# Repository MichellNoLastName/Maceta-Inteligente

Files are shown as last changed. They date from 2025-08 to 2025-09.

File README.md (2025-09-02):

# 🌱 Maceta Inteligente para el Crecimiento de un Crisantemo

Este proyecto fue desarrollado como parte de la asignatura **Proyecto Integrador**, con el objetivo de diseñar y programar una **maceta inteligente** que monitorea y controla las condiciones ambientales necesarias para el óptimo crecimiento de un **crisantemo**.  

La maceta integra sensores, un sistema de riego automático, control de luz artificial y una interfaz LCD para mostrar información en tiempo real, todo gestionado mediante un **Arduino**.

---

## 🚀 Características principales

- 📊 **Monitoreo de temperatura y humedad ambiental** mediante un sensor **DHT11**.  
- 💧 **Control automático de riego** con bomba de agua y sensores de nivel de tanque.  
- ☀️ **Control de fotoperiodo** mediante un sistema de iluminación artificial, activado según el ciclo programado para la planta.  
- 🔔 **Alarmas sonoras** (buzzer) para advertencias de exceso/falta de agua, luz o temperatura.  
- 🖥️ **Pantalla LCD 20x4 con I2C**, que muestra:
  - Fecha y hora (RTC DS1307).  
  - Temperatura y humedad.  
  - Estado del tanque y la luz.  
  - Menú de configuración y selección de planta.  
- 🌼 **Base de datos de parámetros óptimos** para 3 plantas (incluyendo el crisantemo), con rangos de temperatura, humedad y fotoperiodo.  

---

## 🛠️ Componentes utilizados

- **Arduino UNO**  
- **Sensor DHT11** → temperatura y humedad ambiental  
- **Sensor de humedad de suelo** (analógico)  
- **Sensores de nivel de agua** (mínimo y máximo)  
- **Bomba de agua** + relevador para riego automático  
- **LED / lámpara de cultivo** para control de luminosidad  
- **Pantalla LCD 20x4 con módulo I2C**  
- **Módulo RTC DS1307** → control de fecha y hora  
- **Buzzer piezoeléctrico**  
- **Botones de navegación** (izquierda, derecha, enter)  

---

## 📋 Funcionalidades del software

1. **Selección de planta al inicio** (Crisantemo, Rosa de alabastro o Petunia).  
2. **Adquisición de datos en tiempo real** (temperatura, humedad, nivel de agua, fotoperiodo).  
3. **Acciones automáticas**:
   - Activa la bomba de riego si la humedad del suelo es baja.  
   - Activa o apaga la luz según el ciclo fotoperiódico de la planta seleccionada.  
   - Alarmas en caso de exceso de temperatura, sequedad extrema o falta de agua en el tanque.  
4. **Interfaz de usuario en LCD** con menús:
   - Estado actual del sistema.  
   - Parámetros de la planta seleccionada.  
   - Información del sustrato recomendado.  
   - Control manual de la luz.  
   - Activar o desactivar modo silencioso.  
5. **Uso de RTC DS1307** para el control exacto de horarios.  

---

## 📂 Estructura del código

El programa está desarrollado en **C++ para Arduino**, con las siguientes secciones principales:

- Configuración de **pines y sensores**.  
- Inicialización de **LCD y RTC**.  
- **Menú de selección de planta** al inicio.  
- **Loop principal**:
  - Lectura de sensores.  
  - Actualización de pantalla LCD.  
  - Ejecución de alarmas y acciones automáticas.  
- Funciones auxiliares:
  - `read_ds1307()` → lectura del reloj en tiempo real.  
  - `bcd2bin()` → conversión de valores BCD.  
  - `antireboot()` → debounce de botones.  

---

## 📊 Parámetros configurados para el Crisantemo

- 🌡️ **Temperatura óptima**: 10°C – 32°C  
- 💧 **Humedad óptima del suelo**: 65% – 70%  
- ☀️ **Fotoperiodo**: 7:00 a 18:00  
- 🌱 **Sustrato recomendado**:  
  - 2/3 tierra de jardín  
  - 1/3 composta  

---

## 📸 Ejemplo del flujo de trabajo

1. Al encender el sistema, el usuario selecciona la planta en el menú LCD.  
2. El sistema comienza a **monitorear los sensores** y controla automáticamente el riego y la luz.  
3. Si la planta está en riesgo (frío, calor, exceso de agua, falta de tanque), se activa el **buzzer y mensajes en LCD**.  
4. El usuario puede navegar en el menú para ver información o activar/desactivar funciones manualmente.  

---

## 📌 Futuras mejoras

- Comunicación con una **aplicación móvil** vía Bluetooth o WiFi.  
- Registro de datos en **tarjeta SD** para análisis histórico.  
- Implementación de un **modo automático de aprendizaje** que ajuste parámetros según el crecimiento real de la planta.  

---

## 👨‍💻 Autores

Este proyecto fue desarrollado por estudiantes de la asignatura **Proyecto Integrador**, con el objetivo de aplicar conocimientos en:  
- Programación de microcontroladores.  
- Electrónica y sensores.  
- Automatización y control ambiental.  

---
📖 **Asignatura:** Proyecto Integrador  
🌼 **Planta principal de estudio:** Crisantemo  
⚡ **Tecnologías usadas:** Arduino, C++, Electrónica de control  

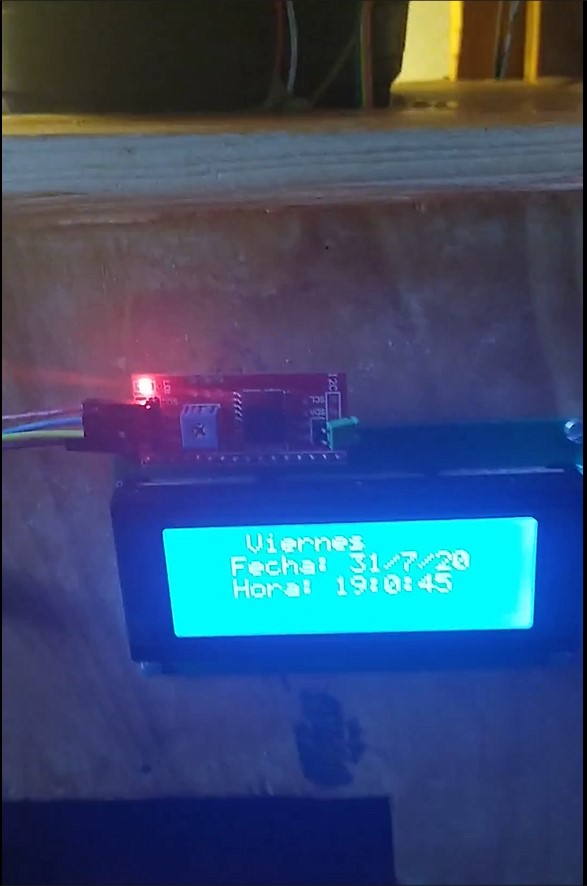
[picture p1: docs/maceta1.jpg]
Maceta 1

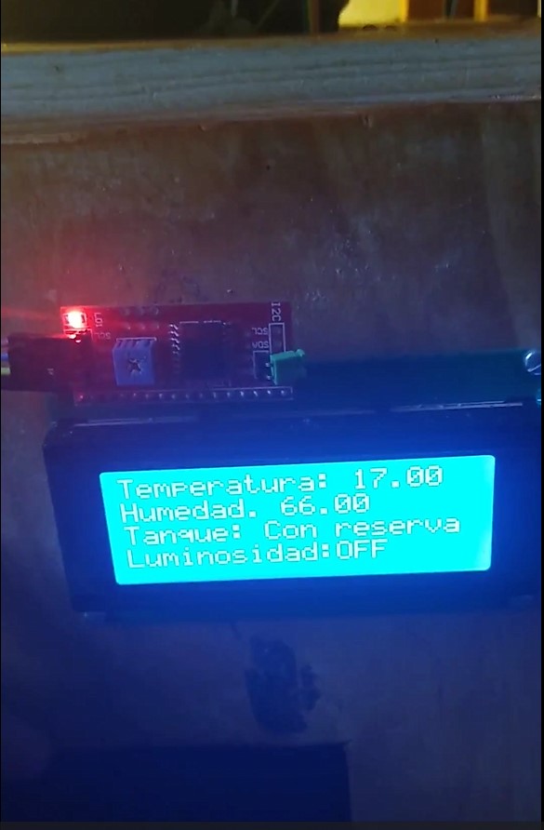
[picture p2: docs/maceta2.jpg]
Maceta 2

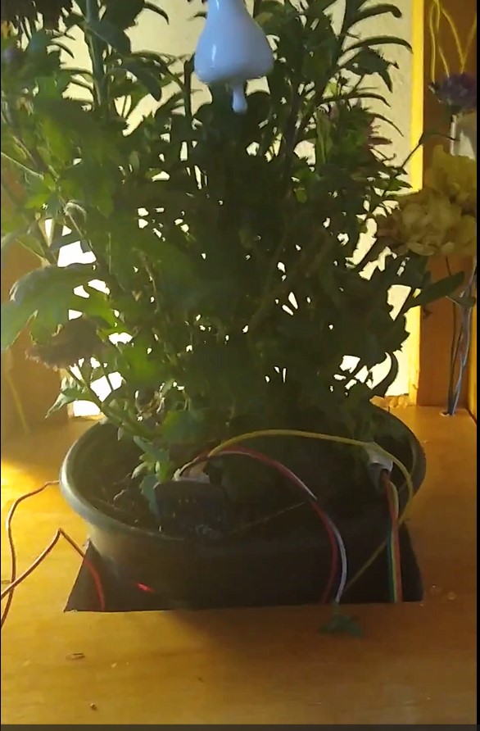
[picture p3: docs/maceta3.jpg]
Maceta 3

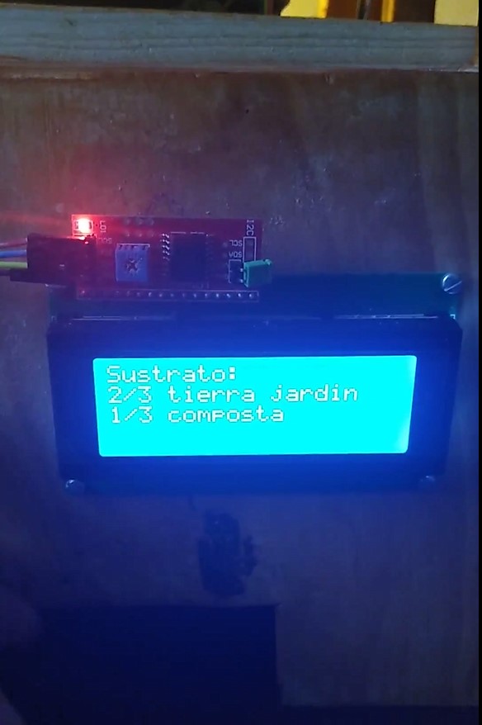
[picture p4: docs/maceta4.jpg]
Maceta 4

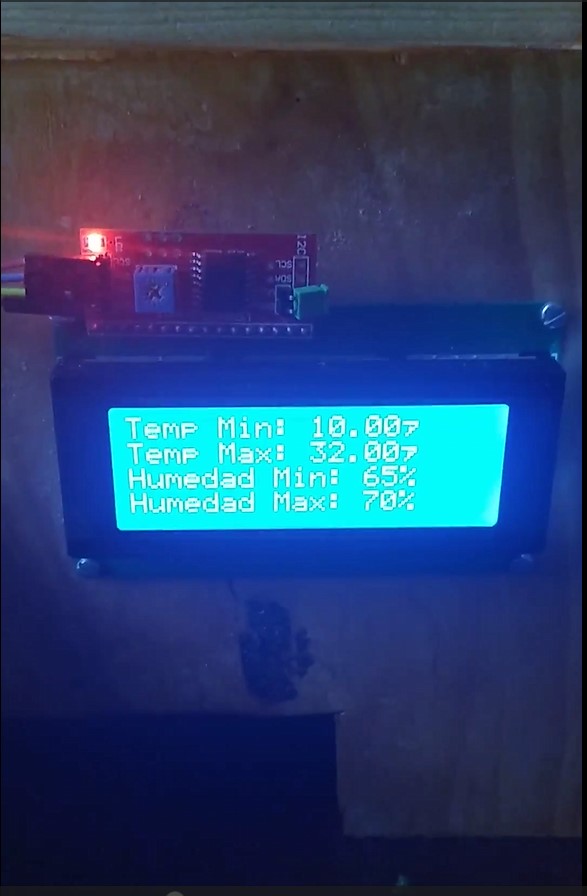
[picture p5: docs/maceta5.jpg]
Maceta 5

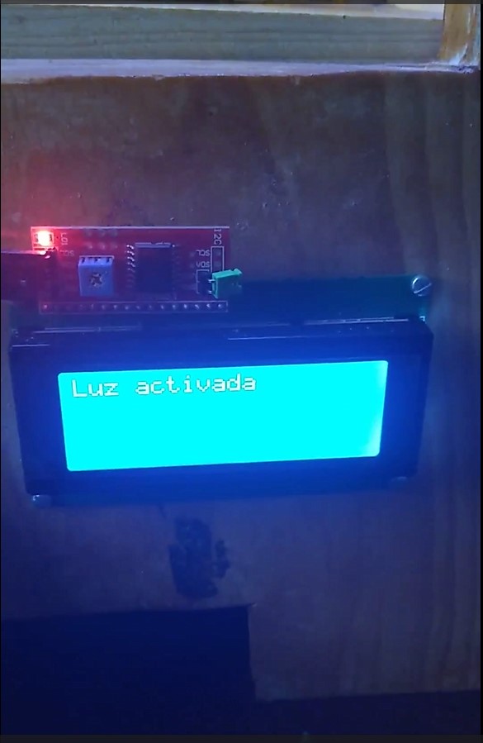
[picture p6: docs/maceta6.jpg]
Maceta 6

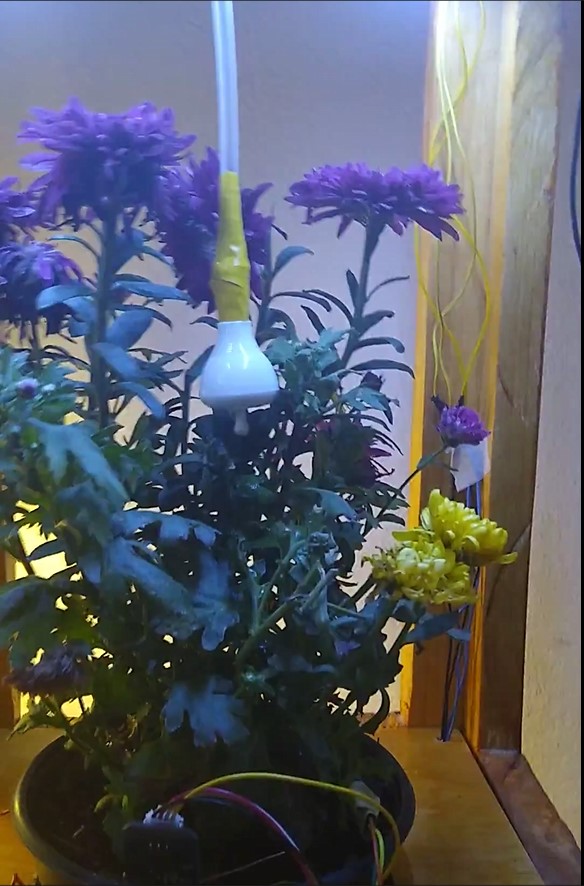
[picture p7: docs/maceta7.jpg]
Maceta 7

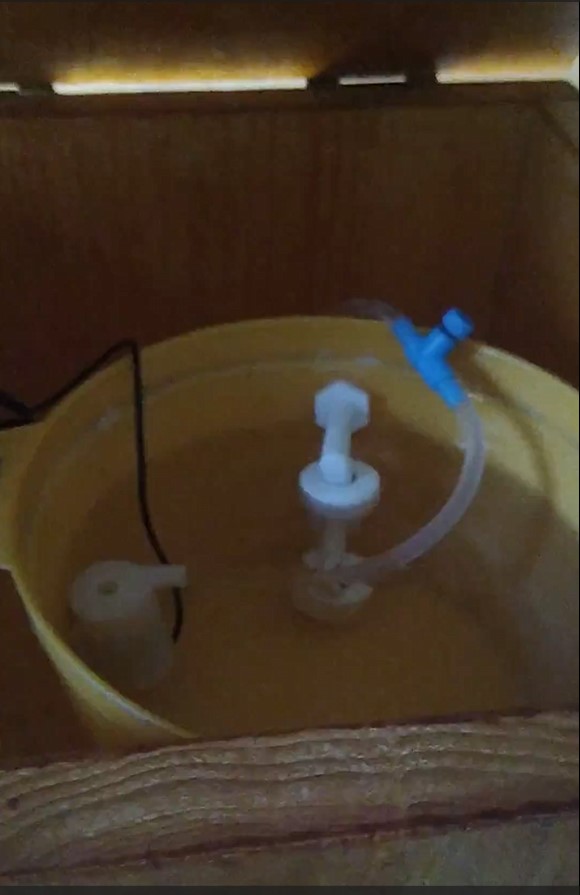
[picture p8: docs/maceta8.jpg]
Maceta 8


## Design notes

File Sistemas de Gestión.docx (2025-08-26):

Sistemas de Gestión

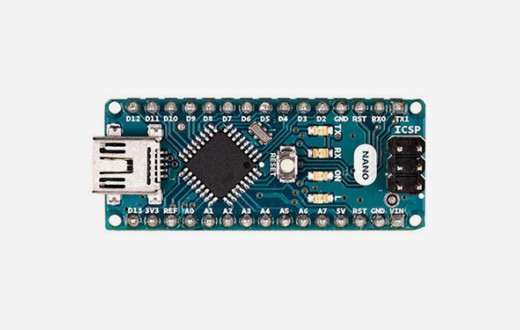
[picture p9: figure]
Arduino Nano

Arduino NANO | | https://store.arduino.cc/usa/arduino-nano

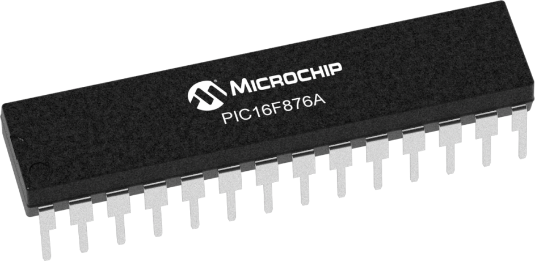
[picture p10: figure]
Resultado de imagen de pic16f876a

PIC16F876A | | https://ww1.microchip.com/downloads/en/devicedoc/39582b.pdf

Sistema de Adquisición de Datos

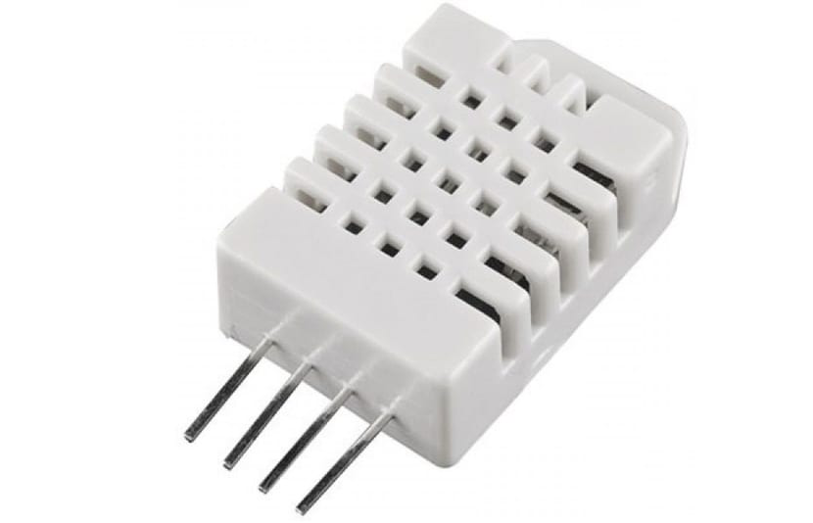
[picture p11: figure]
Resultado de imagen de dht22

DHT22 | | https://naylampmechatronics.com/sensores-temperatura-y-humedad/58-sensor-de-temperatura-y-humedad-relativa-dht22-am2302.html

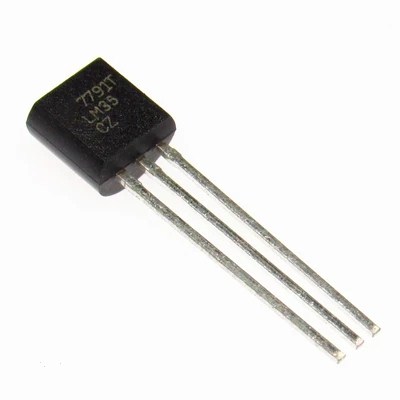
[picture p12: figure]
Resultado de imagen de lm35c

LM35C | | http://www.ti.com/lit/ds/symlink/lm35.pdf

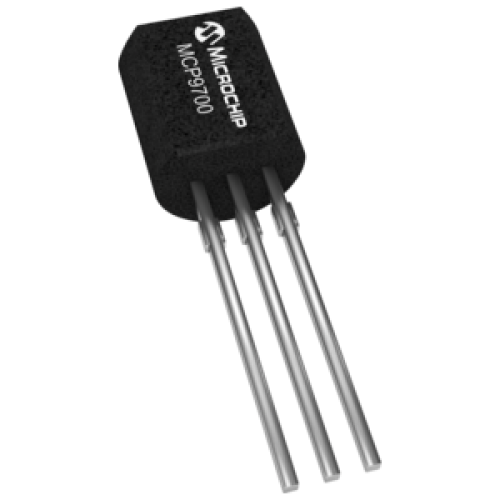
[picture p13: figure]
Resultado de imagen de mcp9700

MCP9700 | | http://ww1.microchip.com/downloads/en/devicedoc/20001942g.pdf

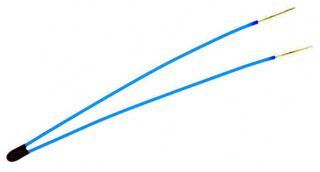
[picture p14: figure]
Resultado de imagen de termistor

NTC B57861S | | https://mexico.newark.com/epcos/b57861s0303f040/thermistor-aec-q200-ntc-30k-th/dp/46WX1275

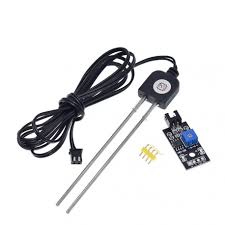
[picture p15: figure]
Resultado de imagen de sensores de humedad de suelo

Sensor de Humedad RFN | | https://articulo.mercadolibre.com.mx/MLM-705838733-sensor-de-humedad-en-suelo-tierra-con-sonda-arduino-_JM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

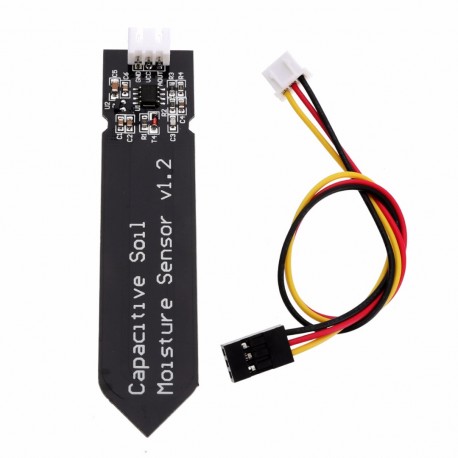
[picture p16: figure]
Sensor Capacitivo de Humedad de Suelo v1.2

Sensor de Humedad Capacitivo | | https://maxelectronica.cl/temperatura-y-humedad/519-sensor-capacitivo-de-humedad-de-suelo-v12.html

Interfaz Grafica

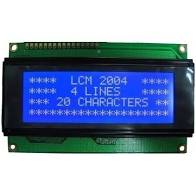
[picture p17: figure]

LCD 20x4 | | https://articulo.mercadolibre.com.mx/MLM-748112446-display-lcd-20x4-arduino-_JM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

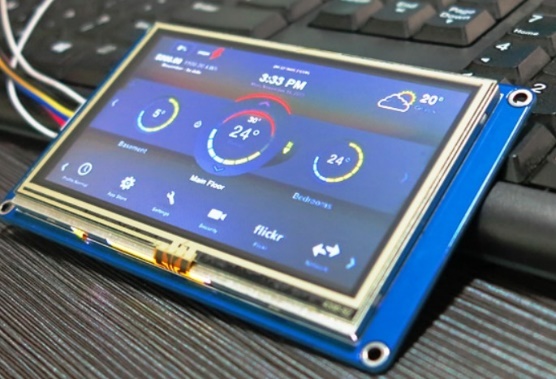
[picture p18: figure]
Resultado de imagen de pantalla nextion

Pantalla Táctil Nextion 2.4 | | https://nextion.tech/

Sistema de Abastecimiento de Agua

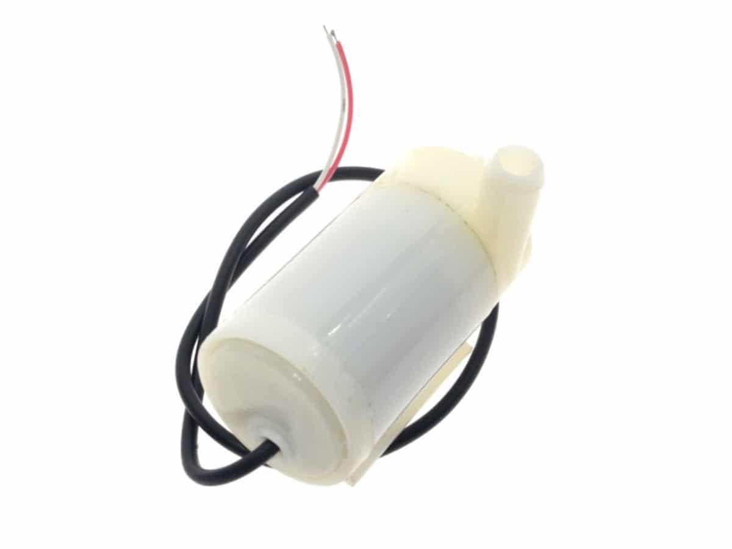
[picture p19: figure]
Resultado de imagen de bomba de agua arduino

Bomba de Agua 6V | | https://www.cdmxelectronica.com/producto/bomba-de-agua-sumergible-arduino-70-120l-h-micro-motor/

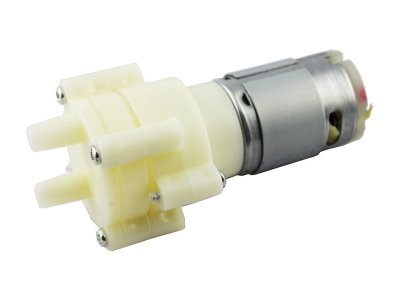
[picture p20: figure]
Resultado de imagen de bomba de agua arduino

Bomba de Agua 12V | | https://articulo.mercadolibre.com.mx/MLM-754341525-mini-bomba-de-agua-de-diafragma-12v-arduino-pic-_JM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

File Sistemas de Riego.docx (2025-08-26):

# Sistemas de Riego

El riego por goteo es muy utilizado en cultivos de hortalizas como jitomate, habanero etc. Aunue también es utilizado oara cultivar hiervas aromáticas y flores.

- Riego por Goteo
1. Goteros Turbulentos:

El gotero turbulento funciona variando los litros por minuto del caudal dependiendo de la presión que esté ejerciendo. Esto implica que no es adecuado cuando hay grandes niveles o pendientes pues en tales casos, el último gotero de la línea no va a recibir el mismo flujo de agua que los primeros.

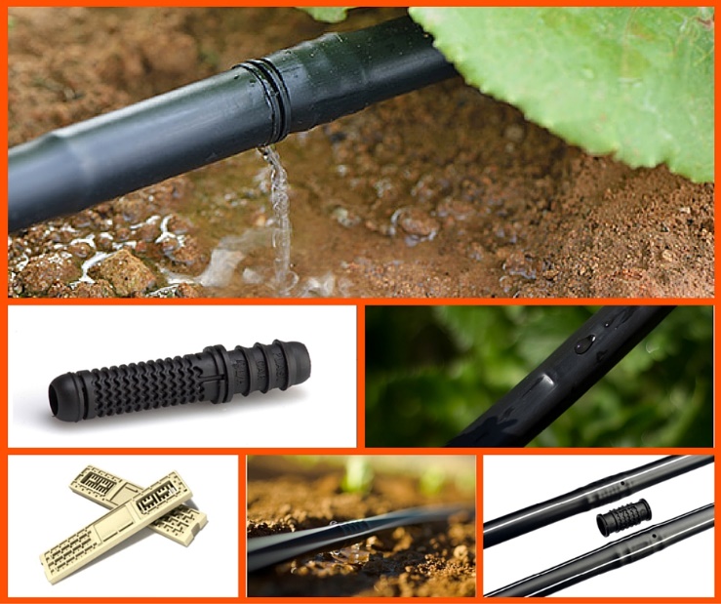
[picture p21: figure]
Resultado de imagen de goteros turbulentos
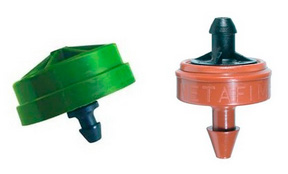
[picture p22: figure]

2. Gotero por válvula

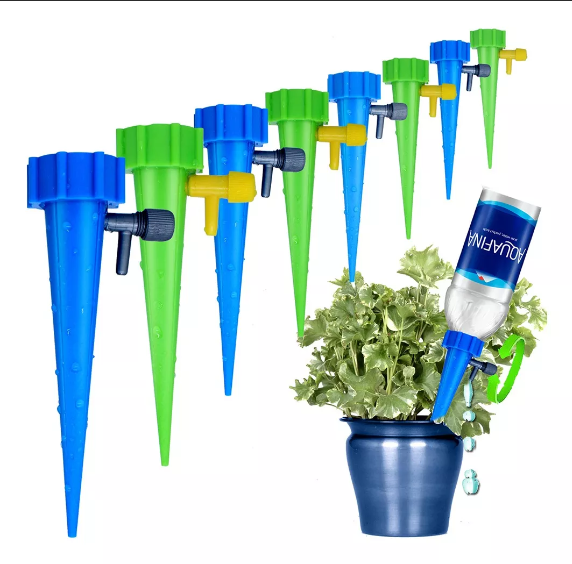
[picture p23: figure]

- Indicadores de Nivel de Agua

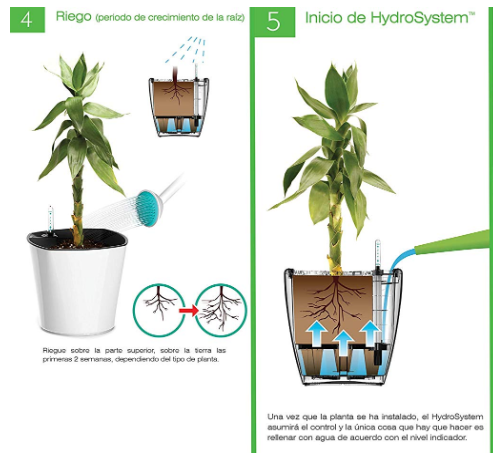
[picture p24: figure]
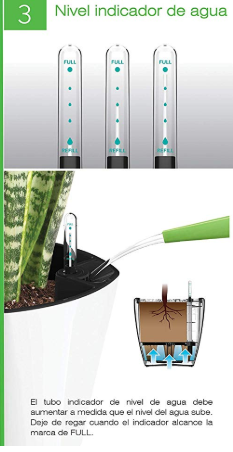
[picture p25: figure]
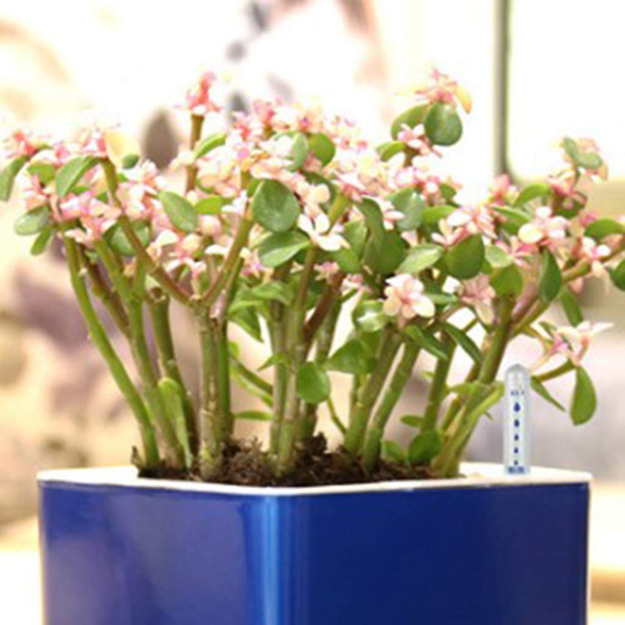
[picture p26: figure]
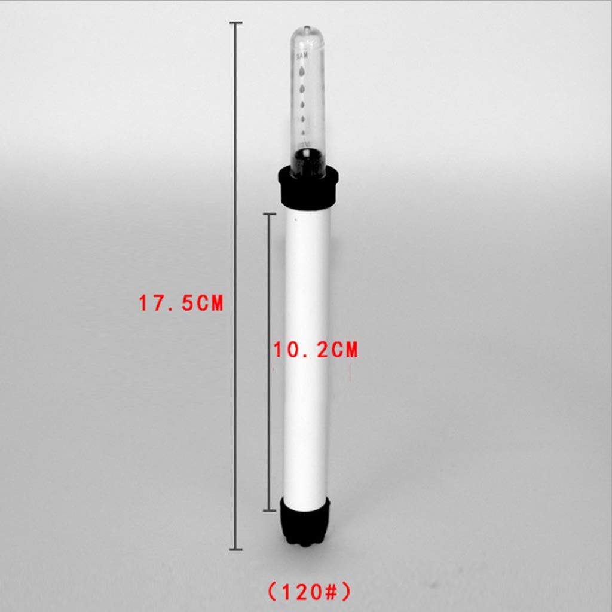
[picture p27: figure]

- Sensores de Humedad de Suelo

Los sensores de humedad consisten en dos placas de cobre separadas, en las cuales registran la humedad en el suelo por medio de un pequeño voltaje que hay de una placa a otra, si esta detecta una resistencia igual a cero indica que el suelo está húmedo, en caso contrario, el suelo está seco.

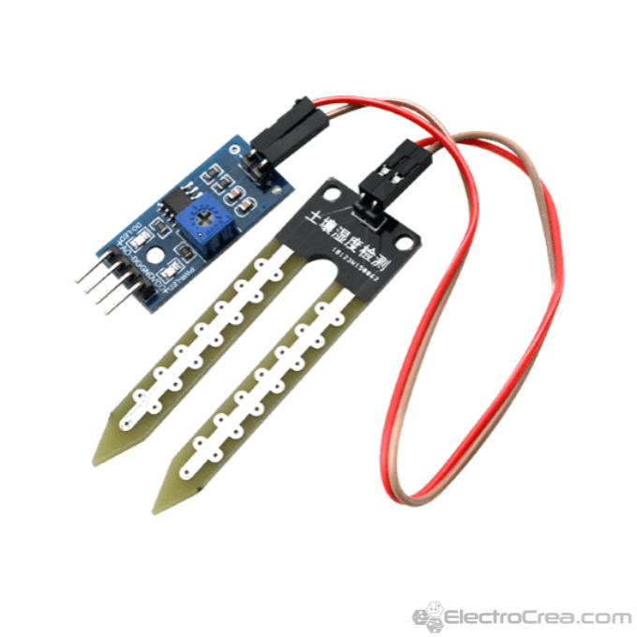
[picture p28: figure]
Resultado de imagen de sensores de humedad
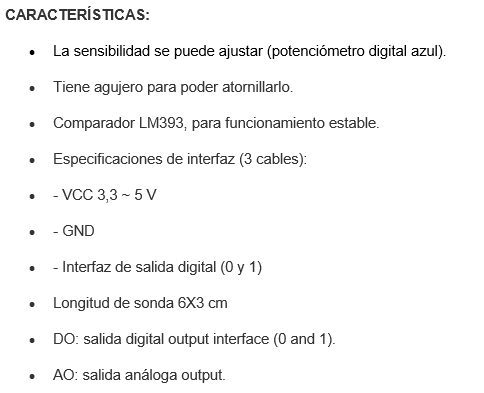
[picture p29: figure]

- Sensor DTH11

Es un dispositivo para medir tanto la humedad relativa como la temperatura. La desventaja de este sensor es que solo proporciona medidas enteras, pero es económico para pequeños proyectos y nos permite obtener dos parámetros.

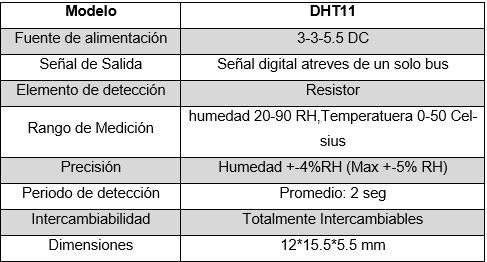
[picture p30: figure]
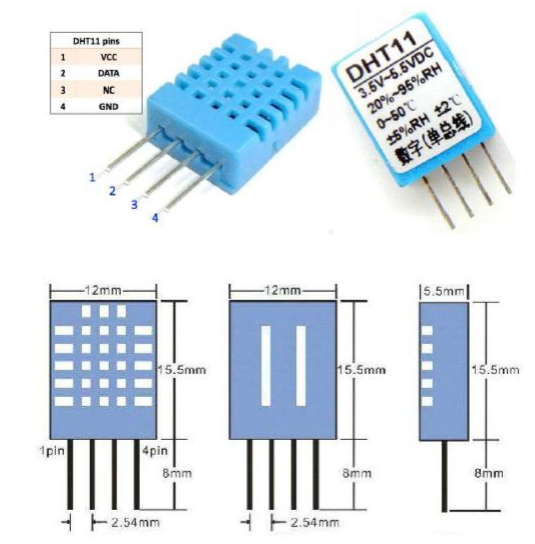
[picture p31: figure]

- Sensor de Temperatura LM35

Es un sensor de temperatura integrado de precisión, el cual su salida es linealmente proporcional a temperatura en °C. El LM35 no requiere ninguna calibración externa o ajuste para proporcionar una precisión típica de +- 1.4°C. Puede ser alimentado con fuente simple o fuente dual, y puede trabajar en un rango de temperaturas de -55° a 150°

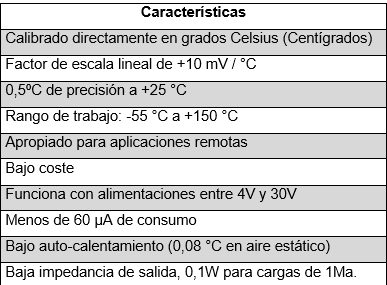
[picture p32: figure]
Resultado de imagen de lm35

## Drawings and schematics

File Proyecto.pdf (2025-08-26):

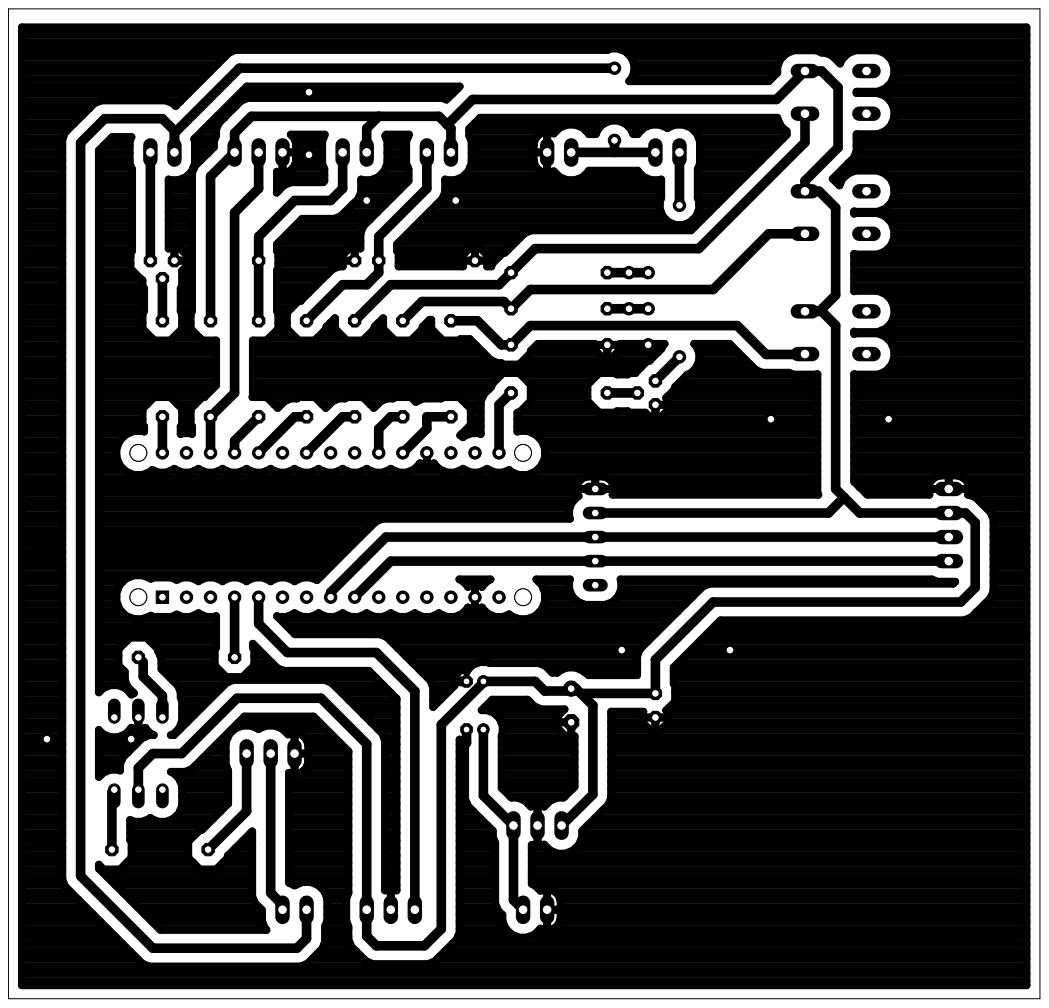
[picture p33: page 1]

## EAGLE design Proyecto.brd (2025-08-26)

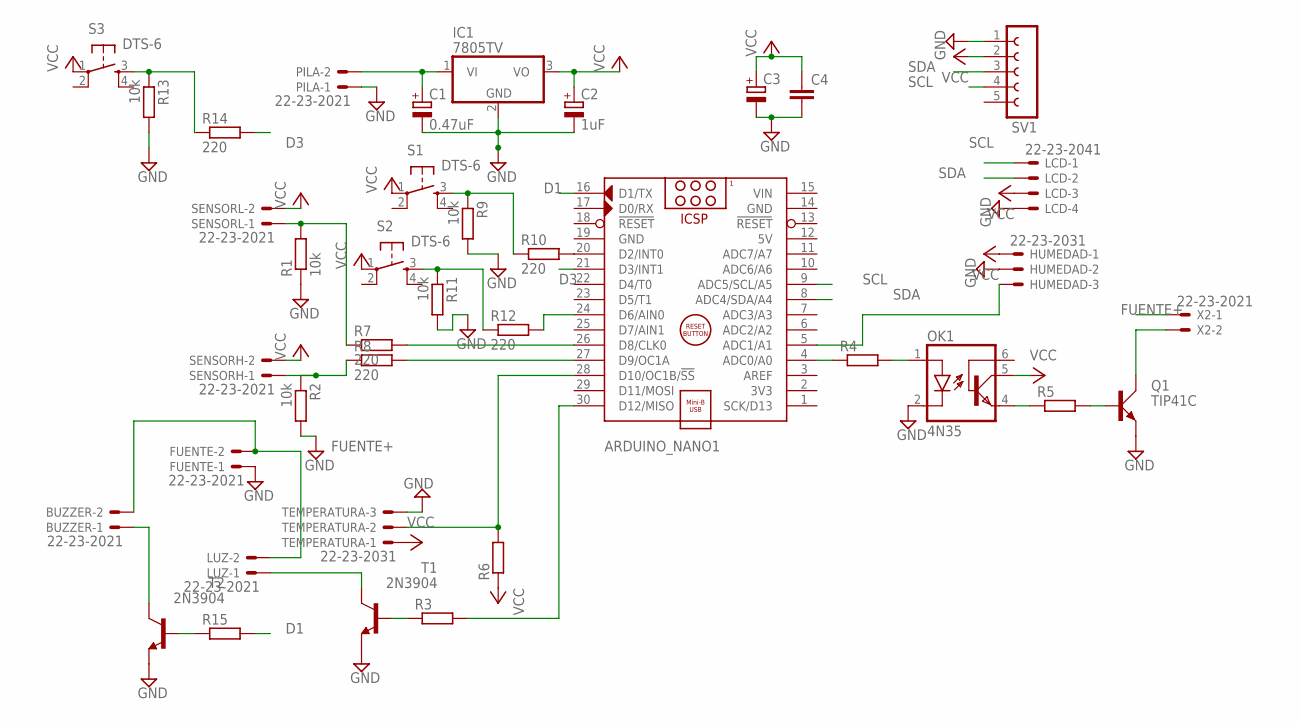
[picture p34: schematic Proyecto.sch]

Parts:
ARDUINO_NANO1: ARDUINO_NANO
BUZZER: 22-23-2021
C1: 0.47uF; E1,8-4
C2: 1uF; E1,8-4
C3: CPOL-EUE3.5-10; E3,5-10
C4: C-EU025-040X050; C025-040X050
FUENTE: 22-23-2021
HUMEDAD: 22-23-2031
IC1: 7805TV; TO220V
LCD: 22-23-2041
LUZ: 22-23-2021
OK1: 4N35; DIL06
PILA: 22-23-2021
Q1: TIP41C; TO220AV
R1, R2, R9, R11, R13: 10k; 0207/10
R3, R4, R5, R6, R15: R-EU_0207/10; 0207/10
R7, R8, R10, R12, R14: 220; 0207/10
S1, S2, S3: DTS-6
SENSORH: 22-23-2021
SENSORL: 22-23-2021
SV1: FE05-1
T1, T2: 2N3904; TO92
TEMPERATURA: 22-23-2031
X2: 22-23-2021

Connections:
5V: ARDUINO_NANO1.12 (5V)
D1: ARDUINO_NANO1.16 (D1/TX), R15.2
D3: ARDUINO_NANO1.21 (D3/INT1), R14.2
FUENTE+: BUZZER.2, FUENTE.2, LUZ.2, X2.1
GND: ARDUINO_NANO1.14 (GND), ARDUINO_NANO1.19 (GND), C1.-, C2.-, C3.-, C4.2, FUENTE.1, HUMEDAD.2, IC1.2 (GND), LCD.4, OK1.2 (C), PILA.1, Q1.E, R1.1, R2.2, R9.2, R11.2, R13.2, SV1.1, T1.3 (E), T2.3 (E), TEMPERATURA.3
unnamed: ARDUINO_NANO1.28 (D10/OC1B/!SS), R6.2, TEMPERATURA.2
unnamed: R1.2, R7.1, SENSORL.1
unnamed: R2.1, R8.1, SENSORH.1
unnamed: LUZ.1, T1.1 (C)
unnamed: R3.1, T1.2 (B)
unnamed: ARDUINO_NANO1.30 (D12/MISO), R3.2
unnamed: Q1.B, R5.2
unnamed: OK1.4 (EMI), R5.1
unnamed: Q1.C, X2.2
unnamed: OK1.1 (A), R4.2
unnamed: ARDUINO_NANO1.4 (ADC0/A0), R4.1
unnamed: ARDUINO_NANO1.27 (D9/OC1A), R8.2
unnamed: ARDUINO_NANO1.26 (D8/CLK0), R7.2
unnamed: C1.+, IC1.1 (VI), PILA.2
unnamed: ARDUINO_NANO1.5 (ADC1/A1), HUMEDAD.3
unnamed: R9.1, R10.1, S1.3
unnamed: ARDUINO_NANO1.20 (D2/INT0), R10.2
unnamed: R11.1, R12.1, S2.3
unnamed: ARDUINO_NANO1.24 (D6/AIN0), R12.2
unnamed: R13.1, R14.1, S3.3
unnamed: BUZZER.1, T2.1 (C)
unnamed: R15.1, T2.2 (B)
SCL: ARDUINO_NANO1.9 (ADC5/SCL/A5), LCD.1, SV1.4
SDA: ARDUINO_NANO1.8 (ADC4/SDA/A4), LCD.2, SV1.3
VCC: C2.+, C3.+, C4.1, HUMEDAD.1, IC1.3 (VO), LCD.3, OK1.5 (COL), R6.1, S1.1, S2.1, S3.1, SENSORH.2, SENSORL.2, SV1.2, TEMPERATURA.1
VIN: ARDUINO_NANO1.15 (VIN)

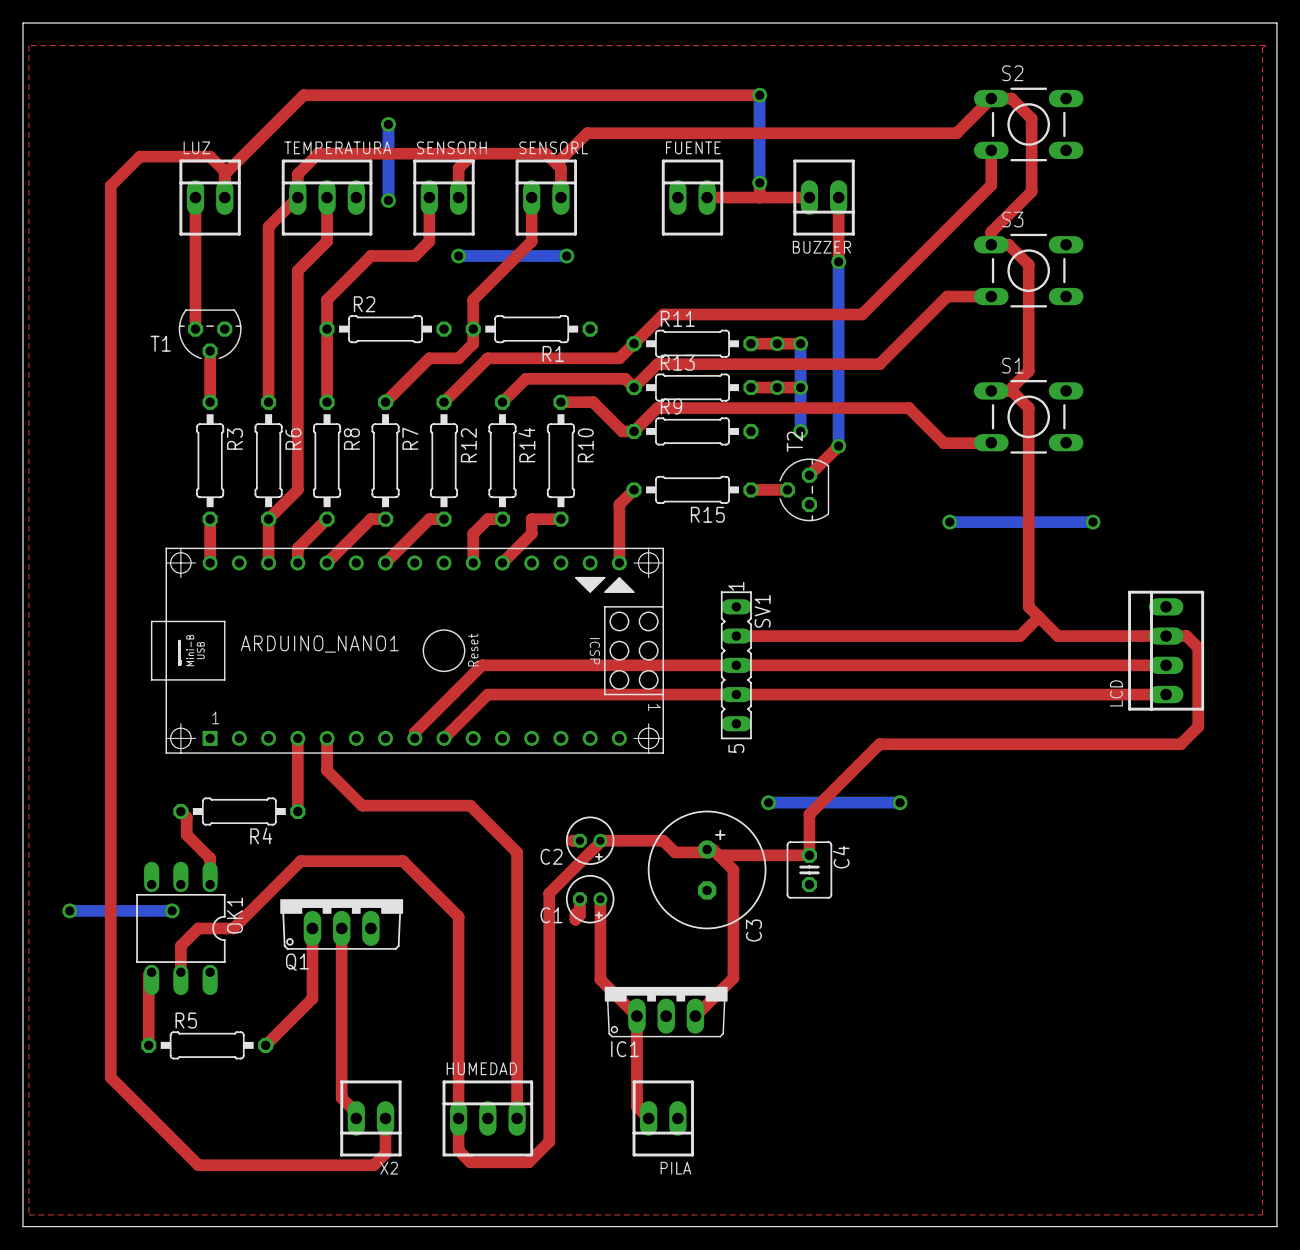
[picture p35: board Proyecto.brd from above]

Board: 2 copper layers, 108.9 x 104.6 mm, 39 parts (0 on the bottom side), 29 nets.

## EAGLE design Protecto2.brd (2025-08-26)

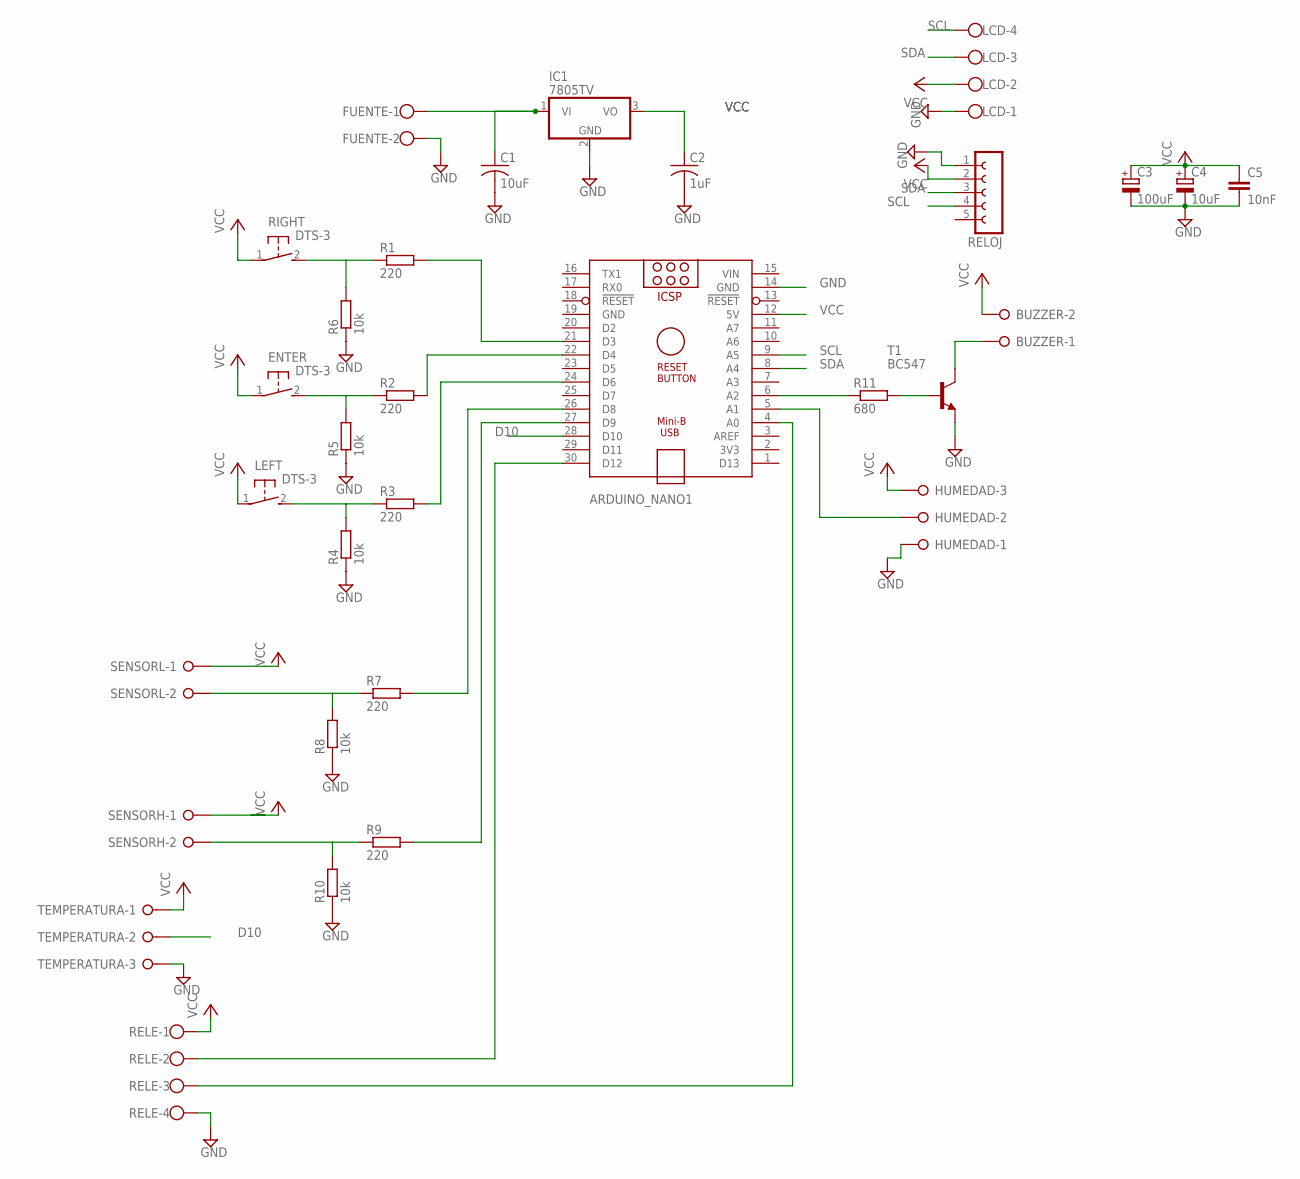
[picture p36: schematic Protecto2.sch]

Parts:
ARDUINO_NANO1: ARDUINO_NANO
BUZZER: W237-02P; W237-132
C1: 10uF; C025-040X050
C2: 1uF; C025-040X050
C3: 100uF; E2,5-7
C4: 10uF; E2-5
C5: 10nF; C025-030X050
ENTER: DTS-3
FUENTE: W237-102
HUMEDAD: W237-3E
IC1: 7805TV; TO220V
LCD: W237-4
LEFT: DTS-3
R1, R2, R3, R7, R9: 220; 0207/10
R4, R5, R6, R8, R10: 10k; 0207/10
R11: 680; 0207/10
RELE: W237-4
RELOJ: FE05-1
RIGHT: DTS-3
SENSORH: W237-02P; W237-132
SENSORL: W237-02P; W237-132
T1: BC547; TO92
TEMPERATURA: W237-3E

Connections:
D10: ARDUINO_NANO1.28 (D10), TEMPERATURA.2
GND: ARDUINO_NANO1.14 (GND), ARDUINO_NANO1.19 (GND), C1.2, C2.2, C3.-, C4.-, C5.2, FUENTE.2, HUMEDAD.1, IC1.2 (GND), LCD.1, R4.1, R5.1, R6.1, R8.1, R10.1, RELE.4, RELOJ.1, T1.1 (E), TEMPERATURA.3
unnamed: R1.1, R6.2, RIGHT.2
unnamed: ENTER.2, R2.1, R5.2
unnamed: LEFT.2, R3.1, R4.2
unnamed: ARDUINO_NANO1.21 (D3), R1.2
unnamed: ARDUINO_NANO1.22 (D4), R2.2
unnamed: ARDUINO_NANO1.24 (D6), R3.2
unnamed: R7.1, R8.2, SENSORL.2
unnamed: R9.1, R10.2, SENSORH.2
unnamed: ARDUINO_NANO1.26 (D8), R7.2
unnamed: ARDUINO_NANO1.27 (D9), R9.2
unnamed: ARDUINO_NANO1.4 (A0), RELE.3
unnamed: ARDUINO_NANO1.30 (D12), RELE.2
unnamed: ARDUINO_NANO1.5 (A1), HUMEDAD.2
unnamed: BUZZER.1, T1.3 (C)
unnamed: R11.2, T1.2 (B)
unnamed: ARDUINO_NANO1.6 (A2), R11.1
unnamed: C1.1, FUENTE.1, IC1.1 (VI)
SCL: ARDUINO_NANO1.9 (A5), LCD.4, RELOJ.4
SDA: ARDUINO_NANO1.8 (A4), LCD.3, RELOJ.3
VCC: ARDUINO_NANO1.12 (5V), BUZZER.2, C2.1, C3.+, C4.+, C5.1, ENTER.1, HUMEDAD.3, IC1.3 (VO), LCD.2, LEFT.1, RELE.1, RELOJ.2, RIGHT.1, SENSORH.1, SENSORL.1, TEMPERATURA.1
VIN: ARDUINO_NANO1.15 (VIN)

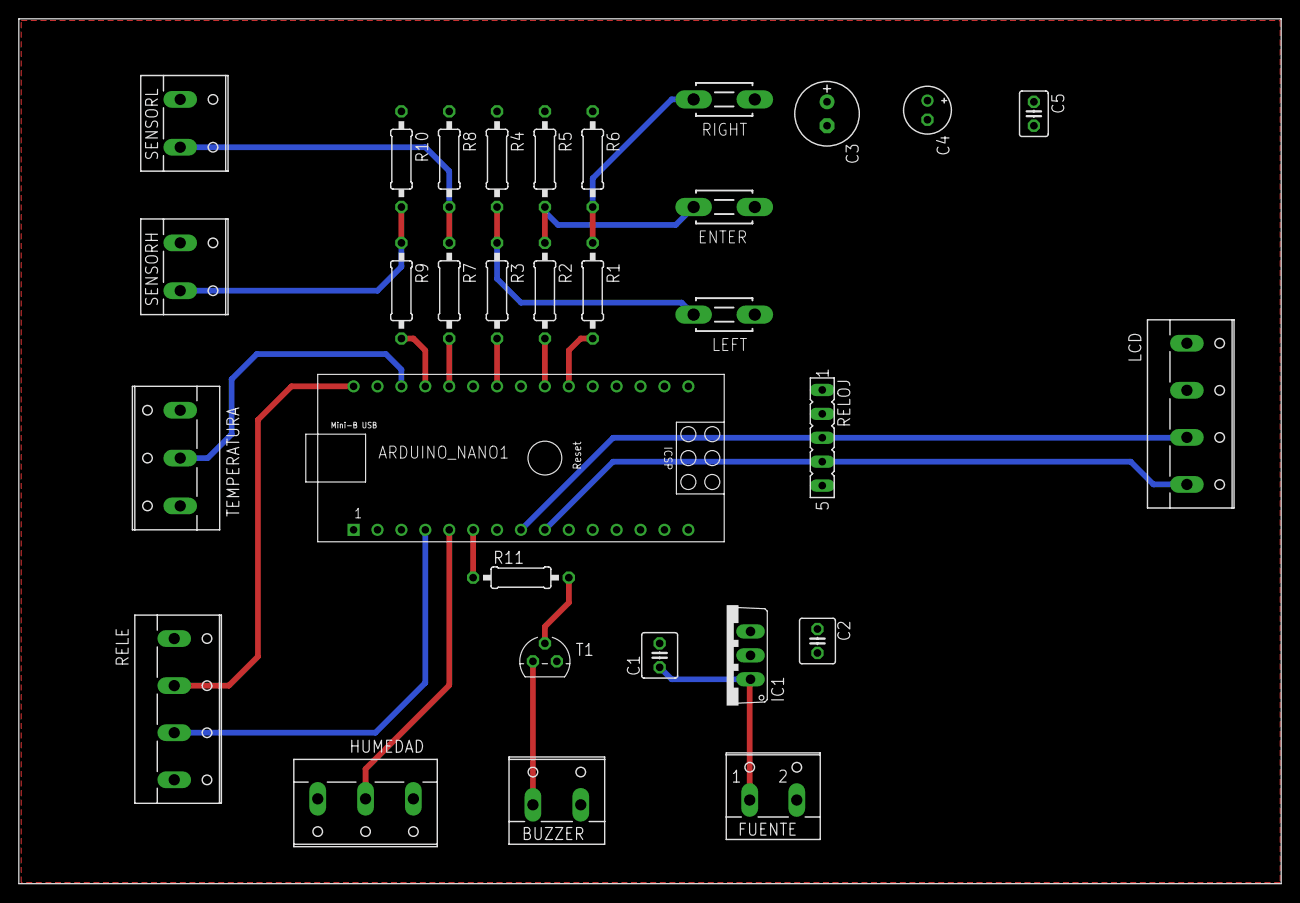
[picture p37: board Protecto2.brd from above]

Board: 2 copper layers, 134.1 x 91.9 mm, 31 parts (0 on the bottom side), 22 nets.

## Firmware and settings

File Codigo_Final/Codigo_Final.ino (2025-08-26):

#include <OneWire.h>
#include <Wire.h>
#include <DHT.h>

#define DHTTYPE DHT11
#define pinHumedad A1
#define pinLum 12
#define pinBomba A0
#define pinBuzzer A2
#define sensorH 9
#define sensorL 8
#include <Wire.h>
#include <LCD.h>
#include <LiquidCrystal_I2C.h>
#define buttonRight 3
#define buttonLeft 6
#define buttonEnter 4
#define DHTPin 10
const int antiTime =10;
int stateButton;
int stateButtonAnt;

int reading; 

LiquidCrystal_I2C lcd (0x27,2,1,0,4,5,6,7,3,POSITIVE);
DHT dht(DHTPin,DHTTYPE);

uint8_t second, minute, hour, wday, day, month, year, ctrl;
int buttons[3] = {buttonRight,buttonLeft,buttonEnter};
String plantas[3] = {"1.-Crisantemo","2.-Rosa de alabastro","3.-Petunia"};
float tempMinimas[3] = {10.0,15.0,0.0}; //En grados Celsuis
float tempMaximas[3] = {32.0,27.0,35.0};
int humMinimas[3] = {65,40,40};       //En porcentaje
int humMaximas[3] = {70,50,60};
int inicioFotoperiodo[3] = {7,7,7};
int finFotoperiodo[3] = {18,17,18};
float temp = 0;
int hum = 0;
String tanque = "";
String lum = "";
float tempAnt = 0;
int humAnt = 0;
String tanqueAnt = "";
String lumAnt = "";
uint8_t secondAnt,minuteAnt,hourAnt,dayAnt,wdayAnt,monthAnt,yearAnt;
int menu = 0;
int plantaSelec = 0;
String stringDay = "";
int stateTanque;
int stateRiego = 0;
int stateLuminosidad = 0;  
int modoSilencioso = 0;
int activacionManual = 0;
int desactivacionManual = 0;
int stateTemp = 0;
int stateHum = 0;
void setup() {
  // put your setup code here, to run once:
  delay(2000);
  Wire.begin();
  pinMode(pinBomba,OUTPUT);
  pinMode(sensorL,INPUT);
  pinMode(sensorH,INPUT);
  pinMode(pinLum,OUTPUT);
  pinMode(pinBomba,OUTPUT);
  pinMode(pinBuzzer,OUTPUT);
  digitalWrite(pinBuzzer,LOW);
  digitalWrite(pinLum,HIGH);
  digitalWrite(pinBomba,HIGH);
 
  int i = 0;
  for(i = 0;i < 2;i++){
    pinMode(buttons[i],INPUT);
    }
  lcd.begin(20,4);
  for(int i = 0; i< 3; i++)
  {
    lcd.backlight();
    delay(250);
    lcd.noBacklight();
    delay(250);
  }
  lcd.backlight(); // terminamos con el backlight on
  lcd.setCursor(6,1);
  lcd.print("MACETA");
  lcd.setCursor(4,2);
  lcd.print("INTELIGENTE");
  delay(3000);
  lcd.clear();
  for(int i = 0; i< 3; i++)
  {
    lcd.backlight();
    delay(250);
    lcd.noBacklight();
    delay(250);
  }
  lcd.backlight(); // terminamos con el backlight on

  while(1)
  {
  lcd.setCursor(0,0);
  lcd.print("Seleccionar planta");
  lcd.setCursor(0,1);
  lcd.print(plantas[0]);
  lcd.setCursor(0,2);
  lcd.print(plantas[1]);
  lcd.setCursor(0,3);
  lcd.print(plantas[2]);
  reading = digitalRead(buttonLeft);
  if(reading)
  {
    plantaSelec = 1;
    lcd.clear();
    lcd.setCursor(0,0);
    lcd.print("Planta seleccionada: ");
    lcd.setCursor(0,1);
    lcd.print("Crisantemo");
    delay(2000);
    break;
    }
  reading = digitalRead(buttonEnter);
  if(reading)
  {
    plantaSelec = 2;
    lcd.clear();
    lcd.setCursor(0,0);
    lcd.print("Planta seleccionada: ");
    lcd.setCursor(0,1);
    lcd.print("Rosa de Alabastro");
    delay(2000);
    break;
    }
  reading = digitalRead(buttonRight);
  if(reading)
  {
    lcd.clear();
    lcd.setCursor(0,0);
    lcd.print("Planta seleccionada: ");
    lcd.setCursor(0,1);
    lcd.print("Petunia");
    delay(2000);
    plantaSelec = 3;
    break;
    }
  }

}

void loop() {
  // put your main code here, to run repeatedly:
  adquisicion:
  read_ds1307();
  float temp = dht.readTemperature();
  float hum = analogRead(pinHumedad);
  hum = map(hum,1024,0,0,100);
  if(digitalRead(sensorL) == LOW and digitalRead(sensorH) == LOW)
  {
    tanque = "Vacio";
    stateTanque = 0;
    }
  else if (digitalRead(sensorH) == LOW and digitalRead(sensorL) ==  HIGH)
  {
    tanque = "Con reserva";
    stateTanque = 1;
  }
  else if(digitalRead(sensorH) == HIGH and digitalRead(sensorL) == HIGH) 
  {
    tanque = "Lleno";
    stateTanque = 1;
  }

  if(stateLuminosidad == 1) lum = "ON";
  else lum = "OFF";

  //Alarma de temperatura
  if(temp < tempMinimas[plantaSelec - 1] and stateTemp == 0)
  {
    lcd.clear();
    lcd.setCursor(6,1);
    lcd.print("Ayuda!!");
    lcd.setCursor(2,2);
    lcd.print("Hace mucho frio");
    if(modoSilencioso == 0){
      while(1){    
        digitalWrite(pinBuzzer,HIGH);
        delay(1000);
        digitalWrite(pinBuzzer,LOW);
        reading = digitalRead(buttonEnter);
        if(reading){
          stateTemp = 1;
          break;
          }
        }
      }
    }
  else if(temp > tempMaximas[plantaSelec -1] and stateTemp == 0)
  {
    lcd.clear();
    lcd.setCursor(6,1);
    lcd.print("Uff!!");
    lcd.setCursor(2,2);
    lcd.print("Que calor hace");
    if(modoSilencioso == 0){
      while(1){
        digitalWrite(pinBuzzer,HIGH);
        delay(1000);
        digitalWrite(pinBuzzer,LOW);
        reading = digitalRead(buttonEnter);
        if(reading)
        {
          stateTemp = 1;
          break;
          }
      }
    }
  }
  else if(hum < humMinimas[plantaSelec -1] and stateHum == 0)
  {
    lcd.clear();
    lcd.setCursor(2,2);
    lcd.print("Me estoy secando :(");
    if(modoSilencioso == 0){
        digitalWrite(pinBuzzer,HIGH);
        delay(1000);
        digitalWrite(pinBuzzer,LOW);
    }
    if(stateRiego == 0){
      lcd.clear();
      lcd.setCursor(0,0);
      lcd.print("Regando....");
      delay(1000);
      lcd.noBacklight();
      delay(1000);
      digitalWrite(pinBomba,LOW);
      delay(1000);
      digitalWrite(pinBomba,HIGH);
      delay(1000);
      lcd.backlight();
      lcd.clear();
      lcd.setCursor(0,1);
      lcd.print("Riego terminado");
      stateRiego = 1;
      delay(2000);
    }
    else
    {
      lcd.clear();
      lcd.setCursor(0,0);
      lcd.print("Llenar Tanque!!!");
      if(modoSilencioso == 0){
        digitalWrite(pinBuzzer,HIGH);
        delay(1000);
        digitalWrite(pinBuzzer,LOW);}
      goto adquisicion;
      }
      stateHum = 1;
  }
  else if(hum > humMaximas[plantaSelec-1] and stateHum == 0)
  {
    lcd.clear();
    lcd.setCursor(6,1);
    lcd.print("Socorro");
    lcd.setCursor(4,2);
    lcd.print("Me ahogo!!!");
    if(modoSilencioso == 0){
    while(1){
      digitalWrite(pinBuzzer,HIGH);
      delay(1000);
      digitalWrite(pinBuzzer,LOW);
      reading = digitalRead(buttonEnter);
      if(reading){
        stateHum = 1;
        break;
        }
    }
  }
}
  if(hour >= inicioFotoperiodo[plantaSelec-1] and hour <= finFotoperiodo[plantaSelec -1] and desactivacionManual == 0)
  {
    digitalWrite(pinLum,LOW);
    stateLuminosidad = 1;
    }
  else{
    if(hour < inicioFotoperiodo[plantaSelec-1] and hour > finFotoperiodo[plantaSelec -1]) desactivacionManual = 0;
    if(activacionManual == 1 and desactivacionManual == 0){
      digitalWrite(pinLum,LOW);
      stateLuminosidad = 1;}
    else{
      digitalWrite(pinLum,HIGH);
      stateLuminosidad = 0;
      }
    }
    
  if(minute == 0 or minute == 15 or minute == 30 or minute == 45 and second == 0){
    stateTemp = 0;
    stateHum = 0;
    stateRiego = 0;
    }
  
  stateButton = digitalRead(buttonRight);
  
  if(stateButton != stateButtonAnt)
  {
    if(antireboot(buttonRight))
    {
      lcd.clear();
      if(menu < 5) menu++;
      else menu = 5;
      }
    }
  stateButton = digitalRead(buttonLeft);
  
  if(stateButton != stateButtonAnt)
  {
    if(antireboot(buttonLeft))
    {
      lcd.clear();
      if(menu > 0) menu--;
      else menu = 0;
      }
    }
  
  switch(menu){
    case 0:
      if(secondAnt != second) lcd.clear();
      if(minuteAnt != minute) lcd.clear();
      if(hourAnt != hour) lcd.clear();
      if(wdayAnt != wday) lcd.clear();
      if(dayAnt != day) lcd.clear();
      if(monthAnt != month) lcd.clear();
      if(yearAnt != year) lcd.clear();
      switch(wday)
      {
        case 1:
          stringDay = "Lunes";
          break;
        case 2:
          stringDay = "Martes";
          break;
        case 3:
          stringDay = "Miercoles";
          break;
        case 4:
          stringDay = "Jueves";
          break;
        case 5:
          stringDay = "Viernes";
          break;
        case 6:
          stringDay = "Sábado";
          break;
        case 7:
          stringDay = "Domingo";
          break;
        }
      lcd.setCursor(4,0);
      lcd.print(stringDay);
      lcd.setCursor(3,1);
      lcd.print("Fecha: ");
      lcd.print(day);
      lcd.print('/');
      lcd.print(month);
      lcd.print('/');
      lcd.print(year);
      lcd.setCursor(1,2);
      lcd.print("  Hora: ");
      lcd.print(hour);
      lcd.print(':');
      lcd.print(minute);
      lcd.print(':');
      lcd.print(second);
      break;
    case 1:
      if(temp != tempAnt) lcd.clear();
      if(hum != humAnt) lcd.clear();
      if(tanque != tanqueAnt) lcd.clear();
      if(lum != lumAnt) lcd.clear(); 
      
      lcd.setCursor(0,0);
      lcd.print("Temperatura: ");lcd.print(temp);
      lcd.setCursor(0,1);
      lcd.print("Humedad. ");lcd.print(hum);
      lcd.setCursor(0,2);
      lcd.print("Tanque: ");lcd.print(tanque);
      lcd.setCursor(0,3);
      lcd.print("Luminosidad:");lcd.print(lum);
      break;
    case 2:
      lcd.setCursor(0,0);
      lcd.print("Temp Min: ");lcd.print(tempMinimas[plantaSelec-1]);lcd.write(167);
      lcd.setCursor(0,1);
      lcd.print("Temp Max: ");lcd.print(tempMaximas[plantaSelec-1]);lcd.write(167);
      lcd.setCursor(0,2);
      lcd.print("Humedad Min: ");lcd.print(humMinimas[plantaSelec-1]);lcd.print("%");
      lcd.setCursor(0,3);
      lcd.print("Humedad Max: ");lcd.print(humMaximas[plantaSelec-1]);lcd.print("%");
      break;
    case 3:
      if(plantaSelec == 1)
      {
        lcd.setCursor(0,0);
        lcd.print("Sustrato:");
        lcd.setCursor(0,1);
        lcd.print("2/3 tierra jardin");
        lcd.setCursor(0,2);
        lcd.print("1/3 composta");
        }
      if(plantaSelec == 2)
      {
        lcd.setCursor(0,0);
        lcd.print("Sustrato:");
        lcd.setCursor(0,1);
        lcd.print("25% tierra hoja");
        lcd.setCursor(0,2);
        lcd.print("25% tierra negra");
        lcd.setCursor(0,3);
        lcd.print("50% tepojal");
        }
      if(plantaSelec == 3)
      {
        lcd.setCursor(0,0);
        lcd.print("Sustrato:");
        lcd.setCursor(0,1);
        lcd.print("60% tierra hoja");
        lcd.setCursor(0,2);
        lcd.print("20% Peat Moss");
        lcd.setCursor(0,3);
        lcd.print("20% tepojal");
        }
      break;
    case 4:
      lcd.setCursor(0,0);
      if(stateLuminosidad == 0){
        lcd.print("Luminosidad: OFF");
        lcd.setCursor(0,1);
        lcd.print("Desea encender?");
        stateButton = digitalRead(buttonEnter);
        if(stateButton != stateButtonAnt)
        {
          if(antireboot(buttonEnter))
            {
              activacionManual = 1;
              desactivacionManual = 0;
              stateLuminosidad = 1;
              digitalWrite(pinLum,LOW);
              lcd.clear();
              lcd.print("Luz activada");
              delay(2000);
              menu = 0;
            }
        }
      }
      else{
        lcd.print("Luminosidad: ON");
        lcd.setCursor(0,1);
        lcd.print("Desea apagar?");
        stateButton = digitalRead(buttonEnter);
        if(stateButton != stateButtonAnt)
        {
          if(antireboot(buttonEnter))
            {
              activacionManual = 0;
              desactivacionManual = 1;
              stateLuminosidad = 0;
              digitalWrite(pinLum,HIGH);
              lcd.clear();
              lcd.print("Luz Desactivada");
              delay(2000);
              menu = 0;
            }
        }
        }
        break;
     case 5:
      lcd.setCursor(0,0);
      if(modoSilencioso == 0){
        lcd.print("Silecio: OFF");
        lcd.setCursor(0,1);
        lcd.print("Desea silenciar?");
        stateButton = digitalRead(buttonEnter);
        if(stateButton != stateButtonAnt)
        {
          if(antireboot(buttonEnter))
            {
              modoSilencioso = 1;
              lcd.clear();
              lcd.print("Silecio Activado");
              delay(2000);
              menu = 0;
            }
        }
      
     }
     else{
        lcd.print("Silecio: OFF");
        lcd.setCursor(0,1);
        lcd.print("Desea desactivar?");
        stateButton = digitalRead(buttonEnter);
        if(stateButton != stateButtonAnt)
        {
          if(antireboot(buttonEnter))
            {
              modoSilencioso = 0;
              lcd.clear();
              lcd.print("Silecio Desctivado");
              delay(2000);
              menu = 0;
            }
        }
  }
    break;
}
  tempAnt = temp;
  humAnt = hum;
  tanqueAnt = tanque;
  lumAnt = lum;
  secondAnt = second;
  minuteAnt = minute;
  hourAnt = hour;
  wdayAnt = wday;
  dayAnt = day;
  monthAnt = month;
  yearAnt = year;

}
bool read_ds1307()
{
  // Iniciar el intercambio de información con el DS1307 (0xD0)
  Wire.beginTransmission(0x68);

  // Escribir la dirección del segundero
  Wire.write(0x00);

  // Terminamos la escritura y verificamos si el DS1307 respondio
  // Si la escritura se llevo a cabo el metodo endTransmission retorna 0
  if (Wire.endTransmission() != 0)
    return false;

  // Si el DS1307 esta presente, comenzar la lectura de 8 bytes
  Wire.requestFrom(0x68, 8);

  // Recibimos el byte del registro 0x00 y lo convertimos a binario
  second = bcd2bin(Wire.read());
  minute = bcd2bin(Wire.read()); // Continuamos recibiendo cada uno de los registros
  hour = bcd2bin(Wire.read());
  wday = bcd2bin(Wire.read());
  day = bcd2bin(Wire.read());
  month = bcd2bin(Wire.read());
  year = bcd2bin(Wire.read());

  // Recibir los datos del registro de control en la dirección 0x07
  ctrl = Wire.read();

  // Operacion satisfactoria, retornamos verdadero
  return true;
}

/**
   Esta función convierte un número BCD a binario. Al dividir el número guardado
   en el parametro BCD entre 16 y multiplicar por 10 se convierten las decenas
   y al obtener el módulo 16 obtenemos las unidades. Ambas cantidades se suman
   para obtener el valor binario.
*/
uint8_t bcd2bin(uint8_t bcd)
{
  // Convertir decenas y luego unidades a un numero binario
  return (bcd / 16 * 10) + (bcd % 16);
}

boolean antireboot  (int pin) {
  int  cont =0;
  boolean state;            // guarda el estado del boton 
  boolean stateAnt;    // guarda el ultimo estado del boton 

  do {
    state = digitalRead (pin);
    if (state != stateAnt){  // comparamos el estado actual 
      cont = 0;                   // reiniciamos el contador 
      stateAnt = state;
    }
    else{
      cont += 1;      // aumentamos el contador en 1
    }
    delay (1);
  }
  while (cont < antiTime);
  return state;
}

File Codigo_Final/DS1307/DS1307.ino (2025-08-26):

/**
   GeekFactory - "INNOVATING TOGETHER"
   Distribucion de materiales para el desarrollo e innovacion tecnologica
   www.geekfactory.mx

   Ejemplo para arduino de escritura de fecha y hora al DS1307 en el
   modulo TinyRTC. Este ejemplo pone a tiempo el reloj con los datos
   provistos en la funcion setup.
*/
#include <Wire.h>

// Declaracion de las variables para almacenar informacion de tiempo
uint8_t second, minute, hour, wday, day, month, year;

/**
   Inicio del sketch: Este codigo se ejecuta al conectar el arduino
*/
void setup() {

  // NOTA: Estas sentencias se requieren para alimentar directamente el
  // chip RTC desde los pines A3 Y A2 (colocar directamente el modulo sobre
  // la tarjeta arduino, sin la necesidad de cablear en Arduino UNO).
  // Si no se quiere hacer esto, se pueden eliminar o comentar sin problemas
  /*pinMode(A5, OUTPUT);
  digitalWrite(A5, HIGH);
  pinMode(A4, OUTPUT);
  digitalWrite(A4, LOW);*/

  // Configurar la comunicacion a 9600 baudios
  Serial.begin(9600);

  // Preparar la librería Wire (I2C)
  Wire.begin();

  // Imprimir encabezado a la terminal
  Serial.println("----------------------------------------------------");
  Serial.println(" EJEMPLO ESCRITURA DE DS1307 EN TINYRTC CON ARDUINO ");
  Serial.println("            http://www.geekfactory.mx               ");
  Serial.println("----------------------------------------------------");

  // Inicializar las variables con el tiempo a cargar en el modulo RTC
  // ¡¡¡ COLOCA AQUI LA FECHA Y HORA QUE QUIERAS GRABAR EN EL RTC !!!
  second = 30;
  minute = 58;
  hour = 20;
  wday = 4;
  day = 30;
  month = 7;
  year = 20;
}

/**
   Ciclo principàl del sketch: Escribir informacion de fecha y hora una sola vez
*/
void loop() {
  // Escribir hora y fecha al RTC
  write_ds1307();

  // Imprimimos la fecha y hora
  Serial.println("Poner a tiempo el DS1307 en Tiny RTC:");
  print_time();

  // Ciclo infinito, no hacemos nada mas
  for (;;);
}

/**
   Esta funcion establece la cominicación con el DS1307 y escribe los registros
   de fecha y hora. Utiliza la información provista en la función setup que debes
   modificar con la fecha y hora actuales
*/
bool write_ds1307()
{
  // Iniciar el intercambio de información con el DS1307 (0x68)
  Wire.beginTransmission(0x68);

  // Escribir la dirección del registro segundero
  Wire.write(0x00);

  // Escribir valores en los registros, nos aseguramos que el bit clock halt
  // en el registro del segundero este desactivado (esto hace que el reloj funcione)
  Wire.write(bin2bcd(second & 0x7F)); // <--- Esto hace que el reloj comience a trabajar
  Wire.write(bin2bcd(minute));
  Wire.write(bin2bcd(hour));
  Wire.write(bin2bcd(wday));
  Wire.write(bin2bcd(day));
  Wire.write(bin2bcd(month));
  Wire.write(bin2bcd(year));

  // Terminamos la escritura y verificamos si el DS1307 respondio
  // Si la escritura se llevo a cabo el metodo endTransmission retorna 0
  if (Wire.endTransmission() != 0)
    return false;

  // Retornar verdadero si se escribio con exito
  return true;
}

/**
   Convierte un numero binario a BCD
*/
uint8_t bin2bcd(uint8_t bin)
{
  return (bin / 10 * 16) + (bin % 10);
}

/**
   Imprime la fecha y hora al monitor serial de arduino
*/
void print_time()
{
  Serial.print("Fecha: ");
  Serial.print(day);
  Serial.print('/');
  Serial.print(month);
  Serial.print('/');
  Serial.print(year);

  Serial.print("  Hora: ");
  Serial.print(hour);
  Serial.print(':');
  Serial.print(minute);
  Serial.print(':');
  Serial.print(second);

  Serial.println();
}

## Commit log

2025-08-26 Carga de archivos del proyecto
    [MacetaInteligente (Autoguardado).xlsx, Protecto2.brd, Protecto2.sch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]
2025-09-02 Se suben imagenes de proyecto
